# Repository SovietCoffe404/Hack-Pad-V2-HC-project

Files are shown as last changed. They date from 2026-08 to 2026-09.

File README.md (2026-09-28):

# HACK-PAD V2

Hiii, well this is my second version of the Hack Pad since the other one was kinda lame though, so I added new functions to it so it's more fun and useful. You can check out the functions down here :D

# Based on:
**https://hackpad.hackclub.com**

## What it does

- 🖥️ **Custom screen** — Showing anything u want, text or image. Upload it by the PC app!
- ⌨️ **4 keys with editable macros** — U can change what every key does, like copy, paste, undo, etc.
- 🌈 **RGB LEDs with configurable color** — Also custom! choose the color u want in the app.
- 🎮 **Secret minigame** — Snake hidden inside the pad itself, with the option to add more games if wanted ˙𐃷˙ 

  `Hint`: Press all keys down at the same time

- 🕹️ **Extra minigames on the PC** — U can add more minigames!
- 🔌 **USB cable** — Only used to configure the pad from the PC app.
- 🔋 **Battery** (14500 Li-ion + TP4056 charging) — u can replace it whenever it's needed.

## Repo structure

```
HACK-PAD/
├── firmware/     C++ firmware (PlatformIO) flashed onto the XIAO
├── pc_app/       Desktop app in Python to configure the pad
├── hardware/     KiCAD and Fusion project (schematic, PCB, 3D models)
| ├── PCB/        KiCAD project
| └── CAD/        3D models
└── production/   Files for manufacturing (Gerber and .STEP files)
```

Each folder has its own README with the details, such like the PINOUT and clarifications about some things you may have doubts on :) 

## Pinout (Seeed XIAO ESP32-C3)

| XIAO pin | Connected to |
|---|---|
| D0–D3 | Buttons SW1–SW4 |
| D4 (SDA) | Data line for the 6 SK6812 LEDs (in parallel, all the same color) |
| D5 (SCL) | OLED RST |
| D6 (TX) | OLED DC |
| D8 (SCK) | OLED SCK |
| D9 (MISO) | OLED CS |
| D10 (MOSI) | OLED MOSI/DIN |

## Communication protocol

The PC app talks to the pad using plain text over USB. The full commands are in the firmware's README, but right here's a quick summary:

```
PING · SET_TEXT · SET_MACRO · SET_COLOR · SET_BRIGHTNESS · SAVE · GET_CONFIG · IMG_START
```
# BOM — HACK-PAD V2

## On-board (populated on the HACK-PAD PCB)

| RefDes | Description | Manufacturer / Part | Qty | Unit Price | Line Total | Supplier |
|---|---|---|---|---|---|---|
| U1 | XIAO ESP32-C3 module (RISC-V, WiFi+BLE) | [Seeed Studio XIAO ESP32C3](https://www.seeedstudio.com/Seeed-XIAO-ESP32C3-p-5431.html) | 1 | $4.99 | $4.99 | Seeed Studio |
| U2 (SCREEN) | 1.5" 128x128 RGB OLED, SPI (SSD1351) | [Waveshare 1.5inch RGB OLED Module](https://www.waveshare.com/1.5inch-rgb-oled-module.htm) | 1 | $20.99 | $20.99 | Waveshare |
| SW1–SW4 | Cherry MX mechanical switch, PCB mount | Cherry MX (any linear/tactile variant) | 4 | $0.35 | $1.40 | [MechanicalKeyboards.co](https://mechanicalkeyboards.com/collections/cherry-switches) |
| D1–D6 | RGB LED, PLCC4 5x5mm | [OPSCO SK6812](https://www.lcsc.com/product-detail/RGB-LEDs-Built-in-IC_OPSCO-Optoelectronics-SK6812_C5378720.html) | 6 | $0.07 | $0.42 | LCSC |
| R1 | Resistor, 330Ω, 1206 SMD | Generic 1206 | 1 | $0.02 | $0.02 | LCSC |
| C1 | Capacitor, 1206 SMD (schematic value: 100nF) | Generic 1206 | 1 | $0.10 | $0.10 | LCSC |
| — | Custom 2-layer PCB | Fabricated from `hardware/*.kicad_pcb` | 1 | $5.00 | $5.00 | [JLCPCB](https://jlcpcb.com/) |

## Off-board (wired in via the VIN header, not on the PCB)

| Description | Manufacturer / Part | Qty | Unit Price | Line Total | Supplier |
|---|---|---|---|---|---|
| TP4056 protected Li-ion charging module (USB-C) | Generic, with protection | 1 | $1.99 | $1.99 | [AliExpress](https://es.aliexpress.com/item/1005008927476478.html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"order"%3A"-1"%2C"spu_best_type"%3A"price"%2C"eval"%3A"1"%2C"fromPage"%3A"search"%7D&pdp_npi=6%40dis%21USD%211.74%211.74%21%21%2111.65%2111.65%21%402103081117886428617766381e0fd2%2112000047233885048%21sea%21MX%217457249807%21X%211%210%21n_tag%3A-29919%3Bd%3Aa5ac4bc3%3Bm03_new_user%3A-29895&curPageLogUid=Qe5zJJ3YYP9L&utparam-url=scene%3Asearch%7Cquery_from%3A%7Cx_object_id%3A1005008927476478%7C_p_origin_prod%3A) |
| 14500 Li-ion rechargeable cell, 3.7V | Generic protected cell | 1 | $6.99 | $6.99 | [Mercado Libre](https://www.mercadolibre.com.mx/bateria-recargable-14500-37v-aa-pilas-paquete-de-5pz/up/MLMU444769361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) |
| Jumper wires | Generic | 1 | $4.99 | $4.99 | [Amazon](https://www.amazon.com.mx/Pruebas-Opcionales-Surtido-Multicolo-Macho-Macho/dp/B0F8K2V18S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ÅMÅŽÕÑ&crid=2FS9WYDOSLELE&dib=eyJ2IjoiMSJ9.crRcIveGq5Dw6rDP8TsgO1dETPBiBBGED-DrAo09-GRAilTQacxppwqxDViYUAY-jR3B_KcH6lcgj1K-tfIU84nO_ciKgtcC6ZQgJShRqth2BKZDS8j-fq_M_uzVEkaHaFCv_eAJsr9aoTBhb2Q0aKqUz7Y5OnCptMHbCzkuZ_h_VzxIN1AAuZdxH5VF6VKSBQSK2pvNOzy734qRTMIaI2mt8i6tOXdPIBouzRZpiuLq350KXtcUkKXS91tydHXCoizO2jGQa5hunUlGqmn3LnBxT9KSzTnNlR9Szy-x-m0.PVsSNEvhWFqVmlIMK_lOHYp4xiS0gu-wmmEk9sWaAvc&dib_tag=se&keywords=cable%2Bdupont&qid=1788641719&sprefix=cables%2Bdupont%2Caps%2C160&sr=8-12&th=1) |

## Enclosure (not included in the subtotal)

| Description | Source | Cost |
|---|---|---|
| 3D-printed case (`hardware/3D_HACK-PAD_Printing.step`) | Print it by yourself, or a service like JLC3DP |

## Subtotal

**On-board + off-board parts: ≈ $47.55** (excludes shipping, taxes, and the case)

## Screen Shots!









3D HACK-PAD

jhjhghcvfgc

3D_HACK-PAD_2026-Aug-27_08-37-06PM-000_CustomizedView8673833641

## License

MIT — see [`LICENSE`](LICENSE). Use, modify, and share the project
freely, with or without credit.

## ★ Special thanks to:
`https://www.printables.com/@wireva` for the keycaps 3d model! :D

`hackclub.com` for the DIY guide and funding! <3

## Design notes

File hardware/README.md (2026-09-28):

# Hardware ( ꩜ ᯅ ꩜;)⁭ ⁭

## `PCB`

| File | What it is |
|---|---|
| `PCB/HACK-PAD V2.kicad_pro` | Project — open this one on KiCad |
| `PCB/HACK-PAD V2.kicad_sch` | Schematic |
| `PCB/HACK-PAD V2.kicad_pcb` | Board layout |
| `PCB/HACK-PAD V2.kicad_prl` | Local project preferences (not critical) |
| `PCB/fp-lib-table` | Footprint library |
| `PCB/Hack Pad-V2 Gerber.zip` | Manufacturing the PCB |
| `PCB/3D HACK-PAD.step` | 3D model of the assembled PCB |

## `CAD/case_models`

| File | What it is |
|---|---|
| `CAD/case_models/3D_HACK-PAD_Assembled.step` | 3D model with all components mounted — basically the full pad for viewing/rendering |
| `CAD/case_models/3D_HACK-PAD_Printing.step` | Simplified 3D model without the electronics — this is the one for 3D-printing the case ᵔ ᵕ ᵔ |
| `CAD/case_models/3D HACK-PAD Top.step` | The top of the case, it keeps everything in place |
| `CAD/case_models/3D HACK-PAD Body.step` | Our main case, it stores all the electronics |
| `CAD/case_models/3D HACK-PAD Battery cover.step` | Cover for the battery compartment |

## `CAD/keycap_models`

Individual `.stl` files, ready to 3D-print. :D

## Pinout

| XIAO pin | Connected to |
|---|---|
| D0–D3 | Buttons SW1–SW4 (to GND, with internal pull-up) |
| D4 (SDA) | Data line for the 6 SK6812 LEDs — **all 6 share the same DIN in parallel on purpose**, which is why they always show the same color |
| D5 (SCL) | OLED RST |
| D6 (TX) | OLED DC |
| D8 (SCK) | OLED SCK (hardware SPI) |
| D9 (MISO) | OLED CS |
| D10 (MOSI) | OLED MOSI/DIN (hardware SPI) |

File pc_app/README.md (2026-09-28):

# App

A Python app I've created to configure our HACK-PAD over USB cable. ◝(ᵔᗜᵔ)◜

## Structure

| File | For what? |
|---|---|
| `hackpad_app.py` | the main app that handles the screen, macros, LEDs and extra games |
| `serial_link.py` | serial_link.py — Handles the USB connection with the pad |
| `image_convert.py` | Converts any image to 128x128 RGB565 |
| `games/snake_game.py` | Extra Snake, played with the PC keyboard |
| `games/memory_game.py` | Themed Simon Says, played with the mouse |
| `requirements.txt` | Dependencies |

## Usage

```bash
cd pc_app
pip install -r requirements.txt
python hackpad_app.py
```

1. Connect the pad over USB, select the port you used for flashing, and click **Connect**.
2. **Screen**: custom text, or upload an image (auto-cropped and scaled
   to 128x128).
3. **Macros**: change what each of the 4 keys does, either with shortcuts or your own text.
4. **LEDs**: a single color (all 6 LEDs move together, by hardware design) + brightness.
5. **Extra games**: launches Snake or Memory, both run on the PC (separate
   from the secret minigame that lives inside the pad itself).

**Important**: You need to press "Save to pad" if you want the text, macros and color to stay after disconnecting the PC.

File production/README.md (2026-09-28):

# Production!

Every file ready for manufacturing! ( ≧ᗜ≦)

## Files

| File | Tipe | What for? |
|---|---|---|
| `Hack_Pad-V2_Gerber.zip` | Gerber (PCB) | PCB manufacturing |
| `3D_HACK-PAD_Body.step` | STEP | 3D print / Body of the Pad |
| `3D_HACK-PAD_Top.step` | STEP | 3D print / Top case for the pad and mount of the switchs |
| `3D_HACK-PAD_Battery_cover.step` | STEP | 3D print / Case for the battery compartment |

## PCB — `Hack_Pad-V2_Gerber.zip`

**From**: KiCad (Pcbnew 10.0.2)

| Parameters | Value |
|---|---|
| Dimensions | 60.05 mm × 91.05 mm |
| Layers | 2 (F.Cu / B.Cu) |
| Thickness | 1.6 mm |
| Pad-to-pad / Pad-to-track / Track-to-track | 0.2 mm |
| Minimum track width | 0.2 mm |

**Zip content:**
- `*-F_Cu.gbr` / `*-B_Cu.gbr` — copper top/bottom
- `*-F_Mask.gbr` / `*-B_Mask.gbr` — solder mask
- `*-F_Paste.gbr` / `*-B_Paste.gbr` — solder paste
- `*-F_Silkscreen.gbr` / `*-B_Silkscreen.gbr` — serigraphy
- `*-Edge_Cuts.gbr` — edge borders of the board
- `*-PTH.drl` / `*-NPTH.drl` — holes and drill job 
- `*-job.gbrjob` — metadata

## Case — STEP files

STEP (AP214), so you can open/edit it in CAD programs like FreeCAD, Fusion 360, SolidWorks, etc. ◝(ᵔᵕᵔ)◜

| Part | File | Notes |
|---|---|---|
| Body | `3D_HACK-PAD_Body.step` | Stores the PCB and is the main case of the project |
| Top case | `3D_HACK-PAD_Top.step` | Closes everything and keeps things on it's place |
| Battery cover | `3D_HACK-PAD_Battery_cover.step` | Stops batteries from falling |

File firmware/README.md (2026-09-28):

# Firmware

## Structure ദ്ദി(ᵔᗜᵔ)

| File | For what? |
|---|---|
| `platformio.ini` | Board config (`seeed_xiao_esp32c3`) and libraries |
| `src/main.cpp` | Starts everything, updates the on-screen indicator |
| `src/config.h` / `config.cpp` | Saves the text, macros and LED color using NVS Preferences |
| `src/display.h` / `display.cpp` | Drives our OLED display |
| `src/leds.h` / `leds.cpp` | Drives the LEDs |
| `src/keys.h` / `keys.cpp` | Reads the 4 buttons, runs macros over, detects the secret combo of keys ;D |
| `src/game_snake.h` / `game_snake.cpp` | The secret minigame |
| `src/serial_protocol.h` / `serial_protocol.cpp` | USB (serial) protocol, is used to talk with the pc_app/ |

## Flashing (PlatformIO + VS Code)

1. Install [VS Code](https://code.visualstudio.com/) and the **PlatformIO IDE** extension.
2. `File > Open Folder` → select the folder (`firmware/`).
3. Connect the XIAO over USB-C.
4. Click the PlatformIO icon → **Upload** (or `Ctrl+Alt+U`).
5. Open the Serial Monitor (115200 baud) and try sending `PING` — it
   should reply `OK HACKPAD v2`.

## Pairing by Bluetooth

1. With the firmware running, open the Bluetooth settings on your
   PC/phone and look for a device named **"HACK-PAD"**.
2. Pair it like any Bluetooth device.
3. Once paired, the top-right corner should turn green. If it doesn't, try connecting again. (¬_¬")
4. The 4 keys send their macros over Bluetooth (it still works for reconfiguring from
   `pc_app/`, in parallel).

## Serial protocol (USB, 115200 baud, plain text `\n`)

```
PING
SET_TEXT <text>
SET_MACRO <1-4> <text or @SHORTCUT>
SET_COLOR <RRGGBB>
SET_BRIGHTNESS <0-255>
SAVE
GET_CONFIG           (now includes a BLE CONNECTED|DISCONNECTED line)
IMG_START            (then send 128*128*2 raw RGB565 bytes, no \n)
```

Preset shortcuts (`@SHORTCUT`): `@COPY @PASTE @CUT @UNDO @REDO @SAVE
@SELECTALL @ALTTAB @ENTER @ESC @TAB`. Any other text is typed out literally.

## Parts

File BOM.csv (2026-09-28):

RefDes | Description | Manufacturer / Part | Qty | Unit Price (USD) | Line Total (USD) | Supplier | Supplier Link | Notes
U1 | XIAO ESP32-C3 module (RISC-V, WiFi+BLE) | Seeed Studio XIAO ESP32C3 | 1 | 4.99 | 4.99 | Seeed Studio | https://www.seeedstudio.com/Seeed-XIAO-ESP32C3-p-5431.html | Main microcontroller; runs firmware
U2 (SCREEN) | 1.5in 128x128 RGB OLED display SPI (SSD1351) | Waveshare 1.5inch RGB OLED Module | 1 | 20.99 | 20.99 | Waveshare | https://www.waveshare.com/1.5inch-rgb-oled-module.htm | 7-pin PH2.0 cable included
SW1-SW4 | Cherry MX mechanical switch (PCB mount) | Cherry MX (linear or tactile, buyer's choice) | 4 | 0.35 | 1.40 | MechanicalKeyboards.com | https://mechanicalkeyboards.com/collections/cherry-switches | Any Cherry MX variant fits the footprint
D1-D6 | Addressable RGB LED PLCC4 5x5mm | OPSCO SK6812 | 6 | 0.07 | 0.42 | LCSC | https://www.lcsc.com/product-detail/RGB-LEDs-Built-in-IC_OPSCO-Optoelectronics-SK6812_C5378720.html | Unit price drops toward $0.044 at higher volume
R1 | Resistor 330 ohm 1206 SMD | Generic 1206 thick-film resistor | 1 | 0.02 | 0.02 | LCSC | https://www.lcsc.com/ | Any 1206 330R part works
C1 | Capacitor 1206 SMD (schematic value: 100nF) | Generic 1206 capacitor | 1 | 0.10 | 0.10 | LCSC | https://www.lcsc.com/
J1 (VIN) | 2-pin 1.00mm pitch header | Generic 1.00mm pitch header | 1 | 0.15 | 0.15 | Generic (LCSC/Amazon) | https://www.lcsc.com/ | Connects the off-board battery/charger
PCB | Custom 2-layer PCB (fabricated from hardware/*.kicad_pcb) | Custom fab | 1 | 5.00 | 5.00 | JLCPCB | https://jlcpcb.com/ | Approx. price for a small prototype batch (5pcs); price drops per-board at higher qty
- | TP4056 protected Li-ion charging module (USB-C) | Generic TP4056 w/ protection | 1 | 1.99 | 1.99 | Amazon | https://www.amazon.com/TP4056/s?k=TP4056 | Off-board; wired to J1 (VIN). Cheaper per-unit in multi-packs
BAT1 | 14500 Li-ion rechargeable cell 3.7V | Generic protected 14500 cell | 1 | 6.99 | 6.99 | Amazon | https://www.amazon.com/14500-battery-3-7v-li-ion-rechargeable/s?k=14500+battery+3.7v+li-ion+rechargeable | Off-board; wired to the TP4056 module
- | Hookup wire for the battery/VIN connection | Generic 22-24AWG wire | 1 | 0.50 | 0.50 | Generic (Amazon) | https://www.amazon.com/ | Short length, a few cm
- | 3D-printed enclosure (see hardware/3D_HACK-PAD_Printing.step) | Printed in-house or via a print service | 1 | N/A | N/A | Your printer or a service (e.g. JLC3DP/Craftcloud) | N/A | Cost depends on filament/service; not included in the subtotal below

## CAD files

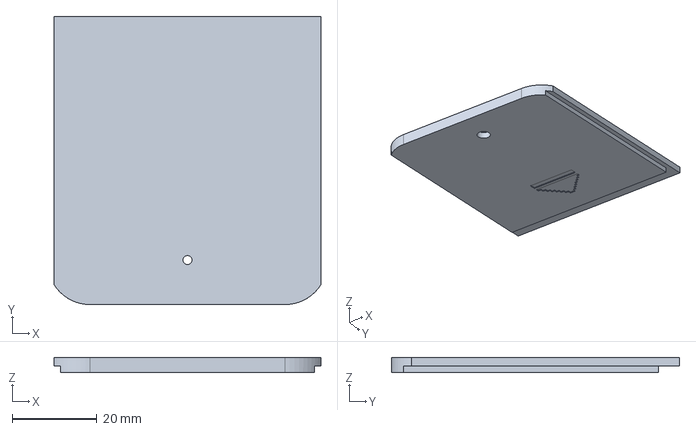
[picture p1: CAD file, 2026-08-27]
hardware/CAD/case_models/3D HACK-PAD Battery cover.step
63.0 x 68.0 x 3.50 mm

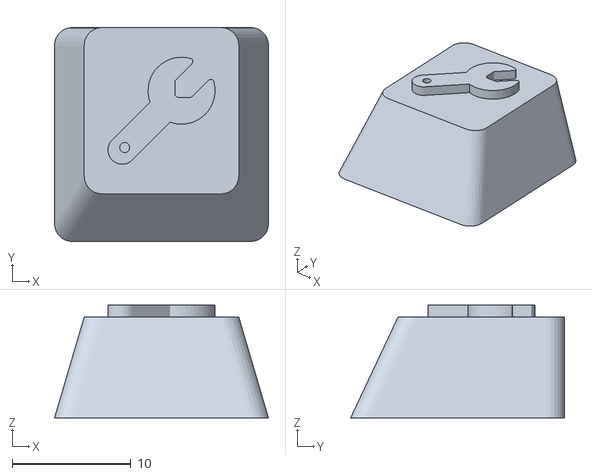
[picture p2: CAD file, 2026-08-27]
hardware/CAD/keycap_models/wrench-solid.stl
18.0 x 18.0 x 9.50

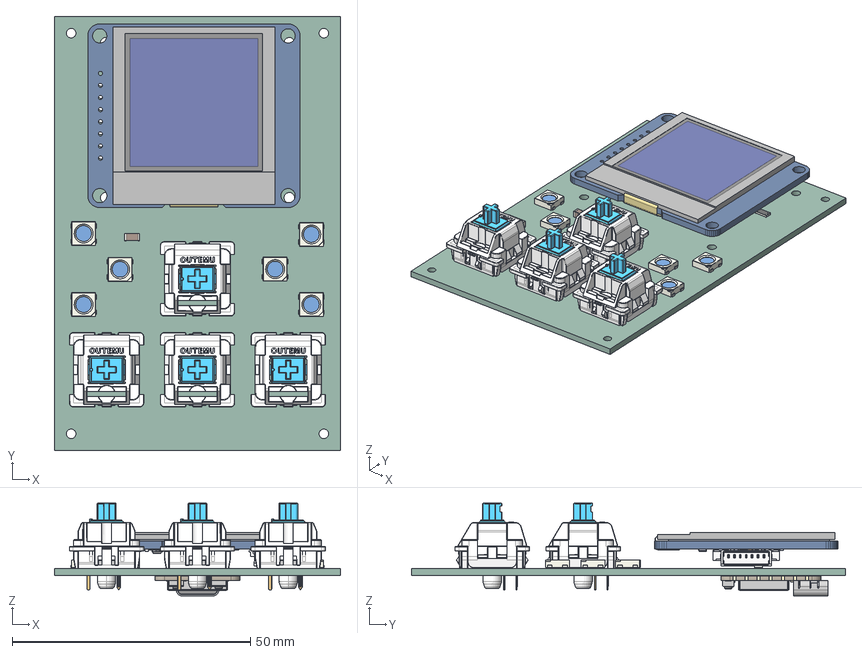
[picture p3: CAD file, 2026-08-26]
hardware/PCB/3D HACK-PAD.step
60.0 x 91.0 x 19.5 mm
R_1206_3216Metric
BOTT x 4
PIN x 4
SPRIN x 4
CLICK x 4
RET x 4
TOP x 4
LED_SK6812_PLCC4_50x50mm_P32mm x 6
C_1206_3216Metric
1_5INCH-2828KSWHG01
1_5INCH_OLED_MODULE_B_PCBA
HP1_25MM-7PIN-SMT
SPONG
BOSS-EXTRUDE14_8_
BOSS-EXTRUDE7_4_
BOSS-EXTRUDE7_3_
BOSS-EXTRUDE14_4_
BOSS-EXTRUDE14_2_
BOSS-EXTRUDE14_11_
BOSS-EXTRUDE7_7_
BOSS-EXTRUDE14_9_
BOSS-EXTRUDE14_3_
BOSS-EXTRUDE14_7_
MIRROR2
BOSS-EXTRUDE14_5_
BOSS-EXTRUDE14_12_
BOSS-EXTRUDE7_8_
BOSS-EXTRUDE7_1_
BOSS-EXTRUDE14_10_
BOSS-EXTRUDE7_9_
BOSS-EXTRUDE14_6_
BOSS-EXTRUDE14_1_
BOSS-EXTRUDE7_6_
BOSS-EXTRUDE7_2_
CUT-EXTRUDE5
BOSS-EXTRUDE7_5_
U.FL Connector v1
Button (1) x 2
Shield
HACK-PAD V2_PCB

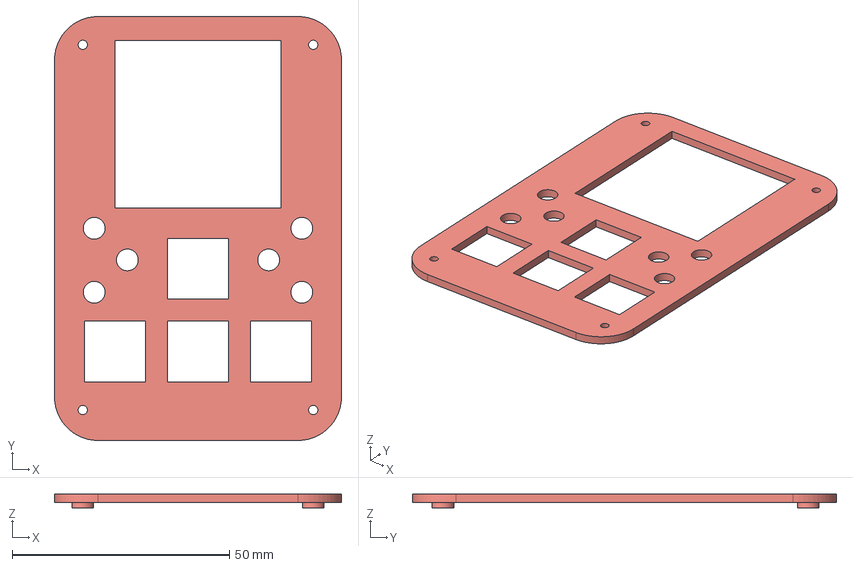
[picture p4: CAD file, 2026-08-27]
hardware/CAD/case_models/3D HACK-PAD Top.step
66.0 x 97.5 x 3.25 mm

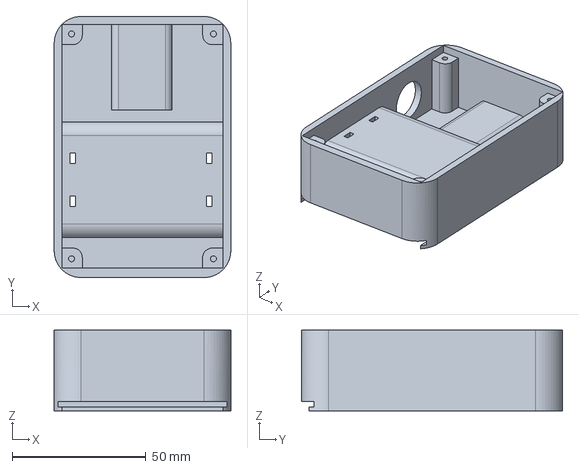
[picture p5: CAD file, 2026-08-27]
hardware/CAD/case_models/3D HACK-PAD Body.step
66.0 x 97.5 x 30.2 mm

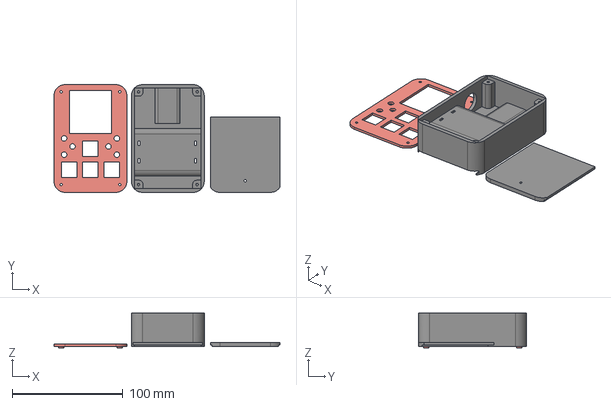
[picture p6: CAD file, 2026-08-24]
hardware/CAD/case_models/3D_HACK-PAD_Printing.step
204.5 x 97.5 x 31.2 mm

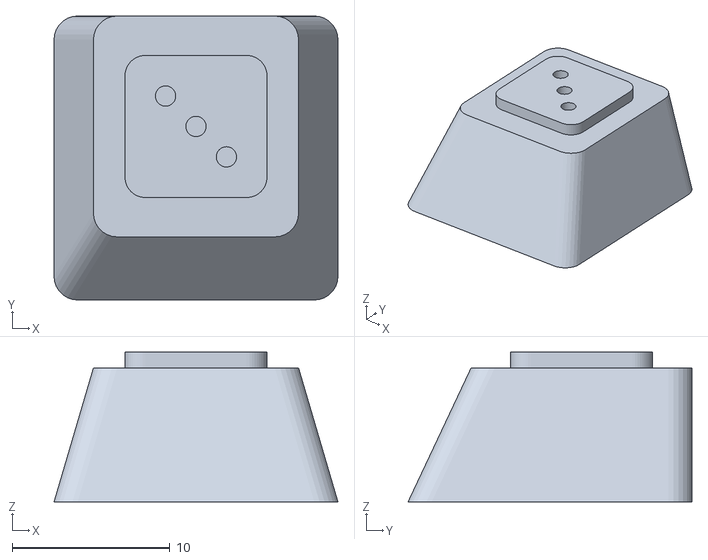
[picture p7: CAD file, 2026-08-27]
hardware/CAD/keycap_models/dice-three-solid.stl
18.0 x 18.0 x 9.50

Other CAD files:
hardware/CAD/keycap_models/pause-solid.stl
hardware/CAD/keycap_models/video-solid.stl
hardware/CAD/keycap_models/arrows-left-right-solid.stl
hardware/CAD/keycap_models/arrow-down-solid.stl
hardware/CAD/keycap_models/house-solid.stl
hardware/CAD/keycap_models/sun-solid.stl
hardware/CAD/keycap_models/vscode.stl
hardware/CAD/keycap_models/rotate-left-solid.stl
hardware/CAD/keycap_models/arrow-pointer-solid.stl
hardware/CAD/keycap_models/maximize-solid.stl
hardware/CAD/keycap_models/drum-solid.stl
hardware/CAD/keycap_models/arrow-left-solid.stl
hardware/CAD/keycap_models/arrow-right-solid.stl
hardware/CAD/keycap_models/arrow-up-solid.stl
hardware/CAD/keycap_models/arrows-rotate-solid.stl
hardware/CAD/keycap_models/arrows-up-down-left-right-solid.stl
hardware/CAD/keycap_models/arrows-up-down-solid.stl
hardware/CAD/keycap_models/atom-solid.stl
hardware/CAD/keycap_models/backward-solid.stl
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

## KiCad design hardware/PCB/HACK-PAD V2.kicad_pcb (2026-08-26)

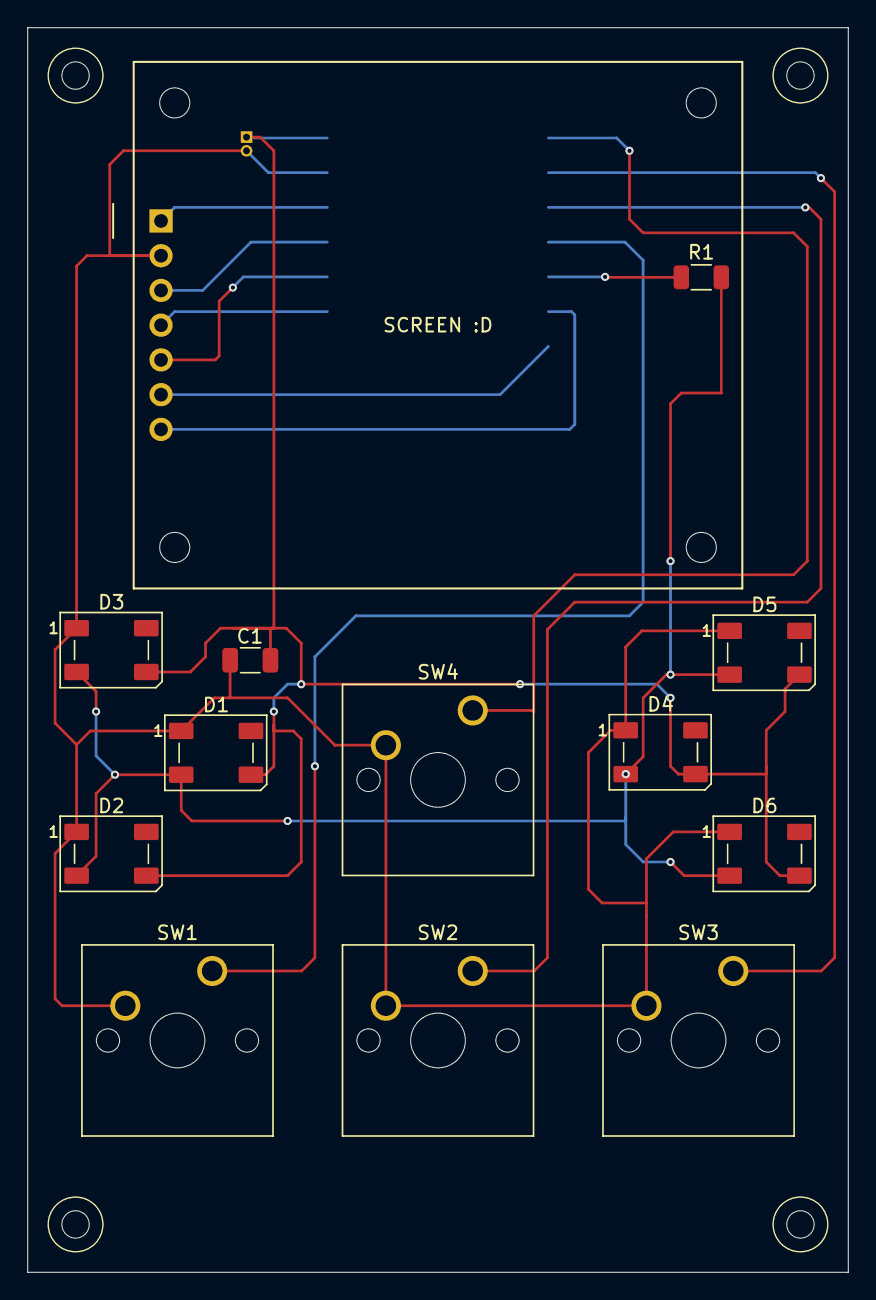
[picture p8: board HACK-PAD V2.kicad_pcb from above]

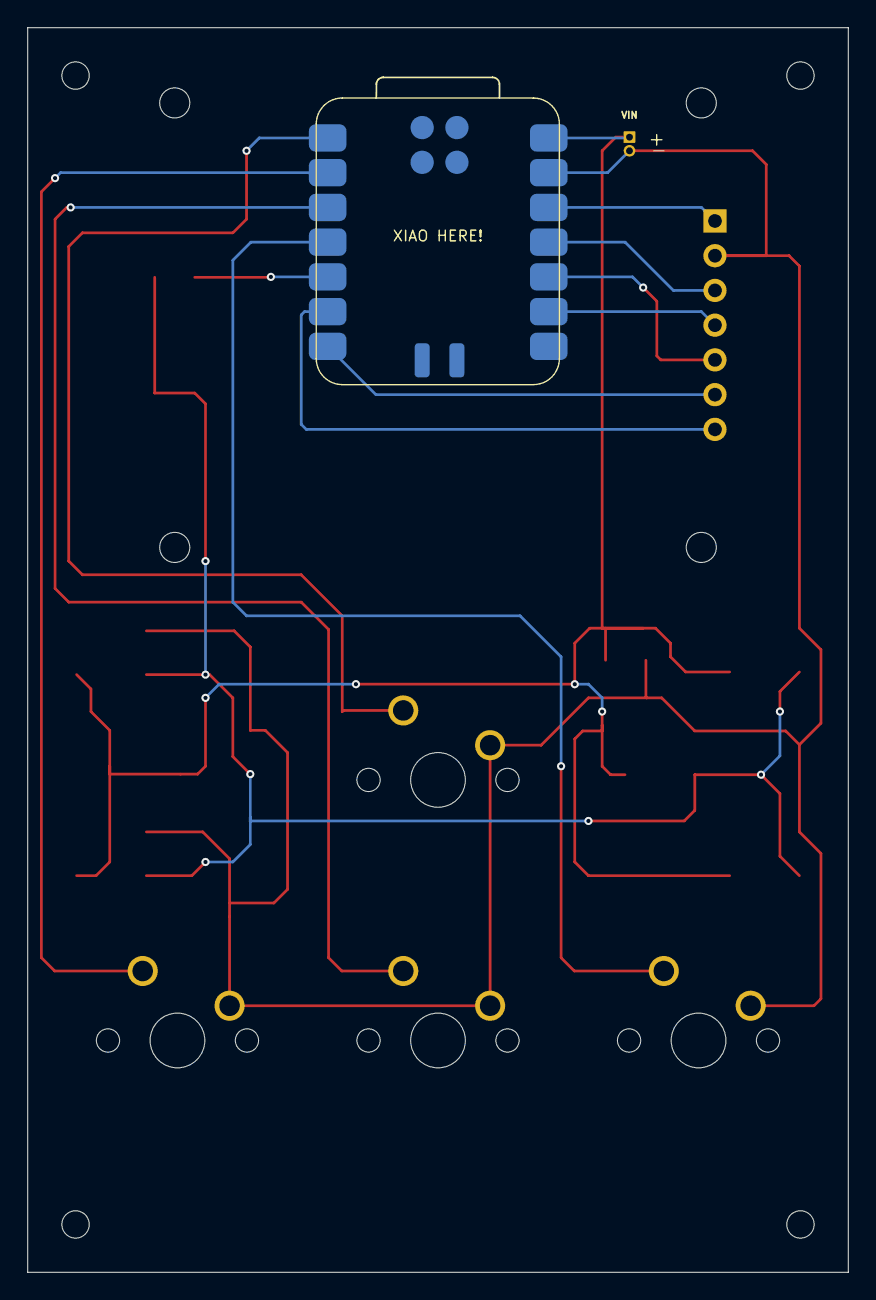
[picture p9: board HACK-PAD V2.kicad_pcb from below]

Board: 2 copper layers, 60.0 x 91.0 mm, 15 parts (2 on the bottom side), 13 nets.

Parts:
C1: 100 nF; C_1206_3216Metric
D1, D2, D3, D4, D5, D6: LED; LED_OPSCO_SK6812_PLCC4_5.0x5.0mm_P3.1mm
R1: 330 ohms; R_1206_3216Metric
SCREEN :D: OLED_1.5inch_RGB_SPI; Waveshare_OLED_1.5inch_ModuleB (5)
SW1, SW2, SW3, SW4: SW_Push; SW_Cherry_MX_1.00u_PCB
VIN: Screw_Terminal_01x02; PinHeader_1x02_P1.00mm_Vertical
XIAO HERE!: MOUDLE-SEEEDUINO-XIAO; XIAO-SAMD21-SMD

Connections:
+5V: C1.1, D1.3, D2.3, D3.3, D4.3, D5.3, D6.3, VIN.1
/CS: SCREEN :D.5 (CS), XIAO HERE!.10 (PA5_A9_D9_MISO)
GND: C1.2, D1.1 (K), D2.1 (K), D3.1 (K), D4.1 (K), D5.1 (K), D6.1 (K), SCREEN :D.2 (GND), SW1.2, SW2.2, SW3.2, SW4.2, VIN.2
unnamed: D1.2 (A), D2.2 (A), D3.2 (A), D4.2 (A), D5.2 (A), D6.2 (A), R1.2
unnamed: SW4.1, XIAO HERE!.1 (PA02_A0_D0)
unnamed: SW3.1, XIAO HERE!.2 (PA4_A1_D1)
unnamed: SCREEN :D.3 (DIN), XIAO HERE!.11 (PA6_A10_D10_MOSI)
unnamed: SCREEN :D.4 (CLK), XIAO HERE!.9 (PA7_A8_D8_SCK)
unnamed: R1.1, XIAO HERE!.5 (PA8_A4_D4_SDA)
unnamed: SCREEN :D.7 (RST), XIAO HERE!.6 (PA9_A5_D5_SCL)
unnamed: SW2.1, XIAO HERE!.3 (PA10_A2_D2)
unnamed: SW1.1, XIAO HERE!.4 (PA11_A3_D3)
unnamed: SCREEN :D.6 (DC), XIAO HERE!.7 (PB08_A6_D6_TX)

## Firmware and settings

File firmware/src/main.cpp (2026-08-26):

#include <Arduino.h>
#include "config.h"
#include "display.h"
#include "leds.h"
#include "keys.h"
#include "serial_protocol.h"
#include "game_snake.h"

static bool lastBleConnected = false;
static uint32_t lastBleCheck = 0;

void setup() {
  Serial.begin(115200);

  config_load();
  display_init();
  leds_init();
  keys_init();        // also starts the BLE keyboard (bleKeyboard.begin())
  protocol_init();

  leds_apply_config();
  display_show_home();
}

void loop() {
  keys_update();
  protocol_update();

  // Updates the BLE status dot on screen every half second, without
  // repainting the whole home screen constantly.
  uint32_t now = millis();
  if (now - lastBleCheck > 500) {
    lastBleCheck = now;
    bool connected = bleKeyboard.isConnected();
    if (connected != lastBleConnected) {
      lastBleConnected = connected;
      display_set_ble_status(connected);
      display_show_home();
    }
  }

  if (keys_secret_combo_triggered()) {
    snake_run(); // blocking until the player exits with SW4
  }
}

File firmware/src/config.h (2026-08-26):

#pragma once
#include <Arduino.h>

// ======================================================================
// PINOUT — same as the wired version (SAMD21): the XIAO ESP32-C3 shares
// the footprint AND the same hardware SPI pins with the rest of the
// XIAO family, so the board wiring didn't change.
// ======================================================================
#define PIN_KEY1      0   // SW1
#define PIN_KEY2      1   // SW2
#define PIN_KEY3      2   // SW3
#define PIN_KEY4      3   // SW4

#define PIN_LED_DATA  4   // D4/SDA -> chain of 6x SK6812 (D1..D6 on the PCB)
#define NUM_LEDS      6

#define PIN_OLED_RST  5   // D5/SCL -> OLED RES
#define PIN_OLED_DC   6   // D6/TX  -> OLED DC
#define PIN_OLED_CS   9   // D9/MISO-> OLED CS
// D8 (SCK) and D10 (MOSI) are the XIAO's hardware SPI, used directly.

#define SCREEN_W 128
#define SCREEN_H 128

// ======================================================================
// Persistent config — on the ESP32-C3 this is stored in NVS (flash) via
// the Preferences library, instead of FlashStorage (that one was
// SAMD21-specific). The custom image still isn't persisted (see README):
// the ESP32-C3 has plenty of flash for that, but it was left as a
// possible future improvement instead of adding it now.
// ======================================================================
struct HackPadConfig {
  char homeText[64];
  char macro[4][40];      // literal text, or "@SHORTCUT" (see keys.cpp)
  uint8_t ledColor[3];    // a single color: the 6 LEDs share DIN in
                           // parallel (on purpose), so they always show
                           // the same color.
  uint8_t brightness;     // 0-255
};

extern HackPadConfig cfg;

void config_load_defaults();
void config_load();   // reads from NVS (or loads defaults if nothing is saved)
void config_save();   // writes to NVS

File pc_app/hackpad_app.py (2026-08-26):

"""
HACK-PAD Companion App
-----------------------
Desktop app (Tkinter) to configure the HACK-PAD over USB:
- Main screen text / image
- Macros for the 4 keys
- Color of the 6 LEDs
- Extra minigames (run on the PC, separate from the pad's secret one)

Requirements: pip install -r requirements.txt
Run:          python hackpad_app.py
"""
import tkinter as tk
from tkinter import ttk, filedialog, colorchooser, messagebox
import subprocess
import sys
import os
import threading

from serial_link import HackPadLink, list_ports
from image_convert import image_to_rgb565_bytes

try:
    from PIL import ImageTk
except ImportError:
    ImageTk = None

APP_DIR = os.path.dirname(os.path.abspath(__file__))


class HackPadApp(tk.Tk):
    def __init__(self):
        super().__init__()
        self.title("HACK-PAD Companion")
        self.geometry("560x560")
        self.link = HackPadLink()

        self._build_connection_bar()

        notebook = ttk.Notebook(self)
        notebook.pack(fill="both", expand=True, padx=8, pady=8)

        self.tab_screen = ttk.Frame(notebook)
        self.tab_macros = ttk.Frame(notebook)
        self.tab_leds = ttk.Frame(notebook)
        self.tab_games = ttk.Frame(notebook)

        notebook.add(self.tab_screen, text="Screen")
        notebook.add(self.tab_macros, text="Macros")
        notebook.add(self.tab_leds, text="LEDs")
        notebook.add(self.tab_games, text="Extra games")

        self._build_screen_tab()
        self._build_macros_tab()
        self._build_leds_tab()
        self._build_games_tab()

    # -------------------------------------------------- connection
    def _build_connection_bar(self):
        bar = ttk.Frame(self)
        bar.pack(fill="x", padx=8, pady=8)

        ttk.Label(bar, text="Port:").pack(side="left")
        self.port_var = tk.StringVar()
        self.port_combo = ttk.Combobox(bar, textvariable=self.port_var, width=18, state="readonly")
        self.port_combo.pack(side="left", padx=4)
        self._refresh_ports()

        ttk.Button(bar, text="Refresh", command=self._refresh_ports).pack(side="left", padx=4)
        self.connect_btn = ttk.Button(bar, text="Connect", command=self._toggle_connect)
        self.connect_btn.pack(side="left", padx=4)

        self.status_lbl = ttk.Label(bar, text="Disconnected", foreground="red")
        self.status_lbl.pack(side="left", padx=12)

    def _refresh_ports(self):
        ports = list_ports()
        self.port_combo["values"] = ports
        if ports and not self.port_var.get():
            self.port_var.set(ports[0])

    def _toggle_connect(self):
        if self.link.is_connected():
            self.link.disconnect()
            self.status_lbl.config(text="Disconnected", foreground="red")
            self.connect_btn.config(text="Connect")
            return
        port = self.port_var.get()
        if not port:
            messagebox.showwarning("HACK-PAD", "Pick a port first.")
            return
        try:
            self.link.connect(port)
            reply = self.link.ping()
            if "OK" not in reply:
                raise RuntimeError(f"Unexpected reply: {reply}")
            self.status_lbl.config(text=f"Connected ({port})", foreground="green")
            self.connect_btn.config(text="Disconnect")
        except Exception as e:
            self.link.disconnect()
            messagebox.showerror("HACK-PAD", f"Could not connect:\n{e}")

    def _require_connection(self):
        if not self.link.is_connected():
            messagebox.showwarning("HACK-PAD", "Connect to the pad first.")
            return False
        return True

    # -------------------------------------------------- screen
    def _build_screen_tab(self):
        f = self.tab_screen
        ttk.Label(f, text="Main screen text:").pack(anchor="w", pady=(10, 2))
        self.text_var = tk.StringVar(value="HACK-PAD")
        entry = ttk.Entry(f, textvariable=self.text_var, width=40)
        entry.pack(anchor="w")
        ttk.Button(f, text="Send text", command=self._send_text).pack(anchor="w", pady=6)

        ttk.Separator(f, orient="horizontal").pack(fill="x", pady=10)

        ttk.Label(f, text="Custom image (auto-cropped/resized to 128x128):").pack(anchor="w")
        ttk.Button(f, text="Choose image and send...", command=self._send_image).pack(anchor="w", pady=6)
        self.preview_lbl = ttk.Label(f, text="(no image)")
        self.preview_lbl.pack(anchor="w", pady=6)

        note = ("Note: the image is drawn instantly but is NOT saved to the\n"
                "pad's internal memory (it's small, the board's RAM isn't\n"
                "enough for that). If the pad loses power, you'll need to\n"
                "resend it from here. Text and macros DO get saved with\n"
                "'Save to pad'.")
        ttk.Label(f, text=note, foreground="#888").pack(anchor="w", pady=10)

        ttk.Button(f, text="Save to pad (text/macros/colors)", command=self._save_to_device).pack(anchor="w", pady=10)

    def _send_text(self):
        if not self._require_connection():
            return
        reply = self.link.set_text(self.text_var.get())
        if "OK" not in reply:
            messagebox.showerror("HACK-PAD", f"Error: {reply}")

    def _send_image(self):
        if not self._require_connection():
            return
        path = filedialog.askopenfilename(filetypes=[("Images", "*.png *.jpg *.jpeg *.bmp *.gif")])
        if not path:
            return
        try:
            raw, pil_img = image_to_rgb565_bytes(path)
        except Exception as e:
            messagebox.showerror("HACK-PAD", f"Could not convert the image:\n{e}")
            return

        if ImageTk is not None:
            thumb = pil_img.copy()
            thumb.thumbnail((96, 96))
            self._preview_img = ImageTk.PhotoImage(thumb)
            self.preview_lbl.config(image=self._preview_img, text="")

        def worker():
            reply = self.link.send_image_rgb565(raw)
            if "OK" not in reply:
                self.after(0, lambda: messagebox.showerror("HACK-PAD", f"Error sending image: {reply}"))

        threading.Thread(target=worker, daemon=True).start()

    def _save_to_device(self):
        if not self._require_connection():
            return
        reply = self.link.save()
        if "OK" in reply:
            messagebox.showinfo("HACK-PAD", "Saved to the pad's memory.")
        else:
            messagebox.showerror("HACK-PAD", f"Error: {reply}")

    # -------------------------------------------------- macros
    MACRO_PRESETS = ["(free text)", "@COPY", "@PASTE", "@CUT", "@UNDO", "@REDO",
                      "@SAVE", "@SELECTALL", "@ALTTAB", "@ENTER", "@ESC", "@TAB"]

    def _build_macros_tab(self):
        f = self.tab_macros
        self.macro_vars = []
        self.macro_preset_vars = []
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

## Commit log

2026-08-24 Initial commit: firmware, PC app y hardware del HACK-PAD V2
    [3D_HACK-PAD_Printing.step, HACK-PAD_V2.kicad_pcb, HACK-PAD_V2.kicad_sch]
2026-08-24 Firmware inalambrico: XIAO SAMD21 -> XIAO ESP32-C3 con teclado BLE
2026-08-25 Remove BOM section from README
    Removed BOM section from the README.
2026-08-26 Revise README for Hack Pad V2 description and features
    Removed outdated information about cable vs Bluetooth functionality and added a personal touch to the introduction.
2026-08-26 Reorganize hardware/ into PCB/ and CAD/
    [3D HACK-PAD.step, 3D_HACK-PAD_Printing.step, BOM.csv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]
2026-08-27 Update Bill of Materials section in README
    Removed pricing details and shipping information from the Bill of Materials section.
2026-08-27 Revise README with HACK-PAD V2 details
    Updated README to include detailed information about the HACK-PAD V2 project, including PCB design, 3D files, and manufacturing instructions.
2026-08-27 Update capacitor value in BOM.csv from 500uF to 100nF
    [BOM.csv]
2026-08-27 Fix capitalization in README.md
    Correct capitalization in the USB cable description.
2026-08-27 Agrega modelo 3D y actualiza el README
2026-09-05 Update RGB LED description in README.md
2026-09-05 Update jumper wires price and subtotal in README
    Updated the price and link for jumper wires in the parts list, and adjusted the subtotal accordingly.
2026-09-28 Revise README for hardware CAD models
    Updated descriptions for CAD models and modified the header.
2026-09-28 Update BOM.csv to remove capacitor note
    Removed a note about the capacitor's value being unusually large for a 1206 package.
    [BOM.csv]
2026-09-28 Fix BOM.csv formatting and update entries
    [BOM.csv]
